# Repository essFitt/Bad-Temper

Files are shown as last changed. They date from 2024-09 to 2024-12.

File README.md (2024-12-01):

This is a remix of the [Temper keyboard](https://github.com/raeedcho/temper). 
The build process and the materials pretty much the same. The reset switch was swapped out for a 6mm tactile button switch. 
To reduce the height of the board, the PCB is not designed to accommodate a base plate. However, I have added a case that is press-fitted and, in my experience, works really well. If printing, you may need to tinker with your tolerances. 

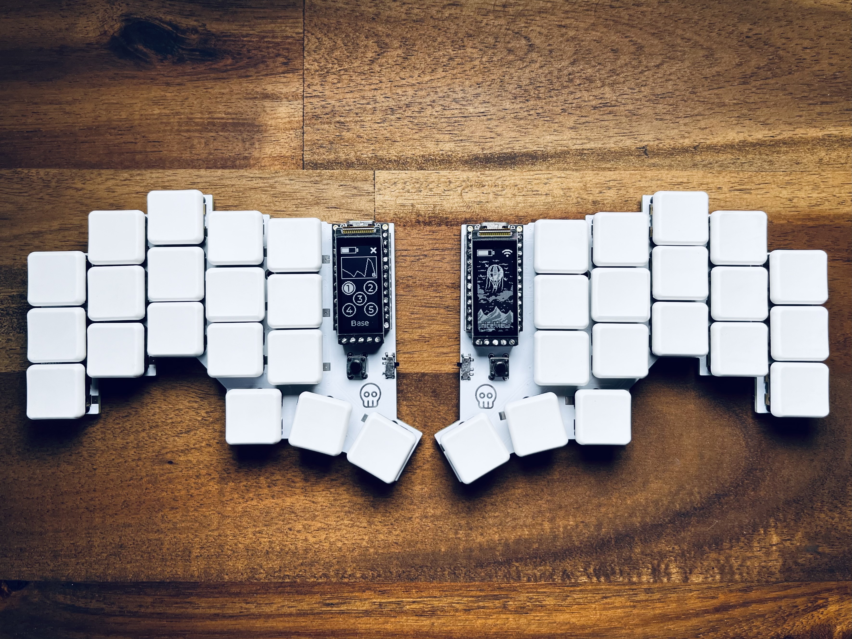
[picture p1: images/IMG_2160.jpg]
Bad Temper top view

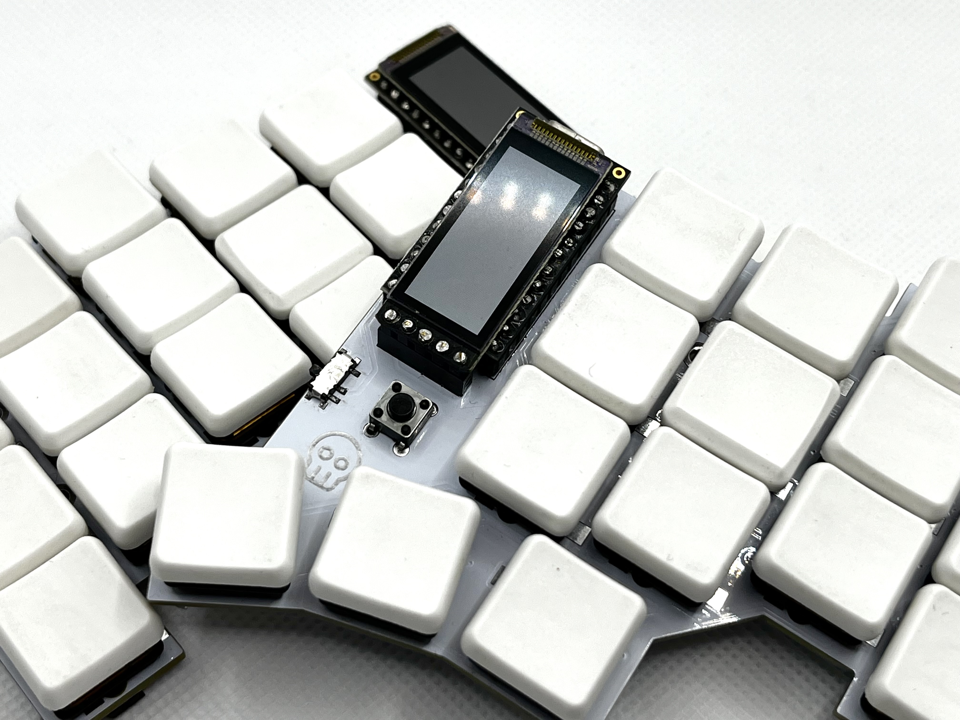
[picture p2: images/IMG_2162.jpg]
Bad Temper close up


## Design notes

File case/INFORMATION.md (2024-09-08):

Please note that the board is not designed to be used with a base plate. I have added a base plate STL file in case anyone wants to edit the PCB to make it work. 
I have found that the switches fit so nicely into the PCB that I do not need a switch plate. They are very snug with no wobble and no chance they will come loose unless deliberately made to do so.

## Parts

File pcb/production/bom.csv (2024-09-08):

Designator | Footprint | Quantity | Value | LCSC Part #
BT1 | Battery_pads_reversible | 1 | Battery_Cell
D1, D10, D11, D12, D13, D14, D15, D16, D17, D18, D2, D3, D4, D5, D6, D7, D8, D9 | D_SMD_TH | 18 | D
J2 | nice_view_jumpers | 1 | nice_view
PWR_SW1 | power_switch_padreverse | 1 | SW_SPDT
RSW1 | SW_PUSH_6mm | 1 | SW_PUSH
SW1, SW10, SW11, SW12, SW13, SW14, SW15, SW16, SW17, SW18, SW2, SW3, SW4, SW5, SW6, SW7, SW8, SW9 | Kailh_socket_PG1350_reversible | 18 | SW_PUSH
U1 | ProMicro_jumpers | 1 | nice_nano

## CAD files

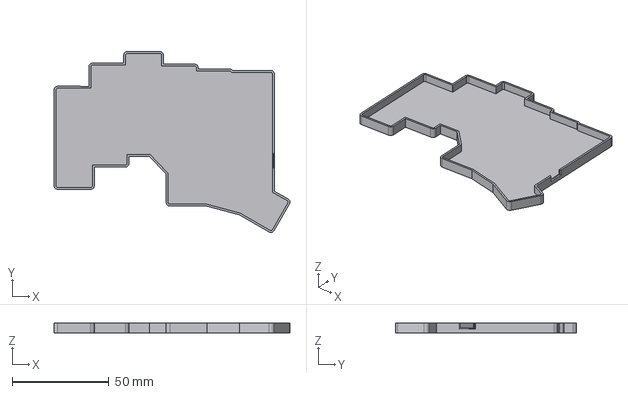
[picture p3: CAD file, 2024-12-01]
case/Case.step
122.0 x 93.6 x 5.00 mm

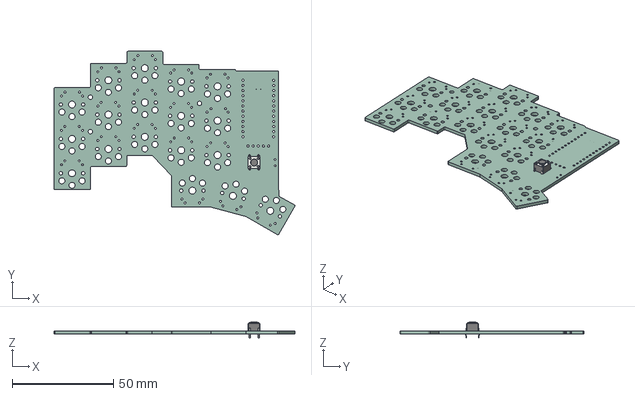
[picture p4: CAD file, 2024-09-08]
pcb/BadTemper.step
119.2 x 90.8 x 7.80 mm
SW_PUSH_6mm
CustomTemper_PCB

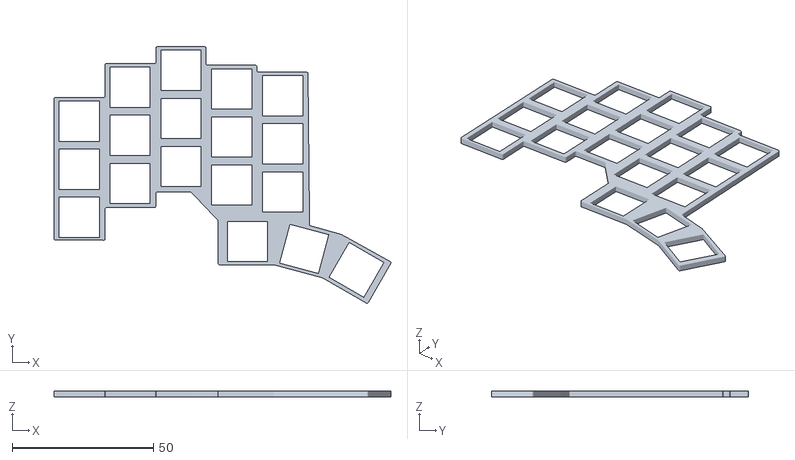
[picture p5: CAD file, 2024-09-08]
case/plate.stl
119.2 x 90.8 x 2.00

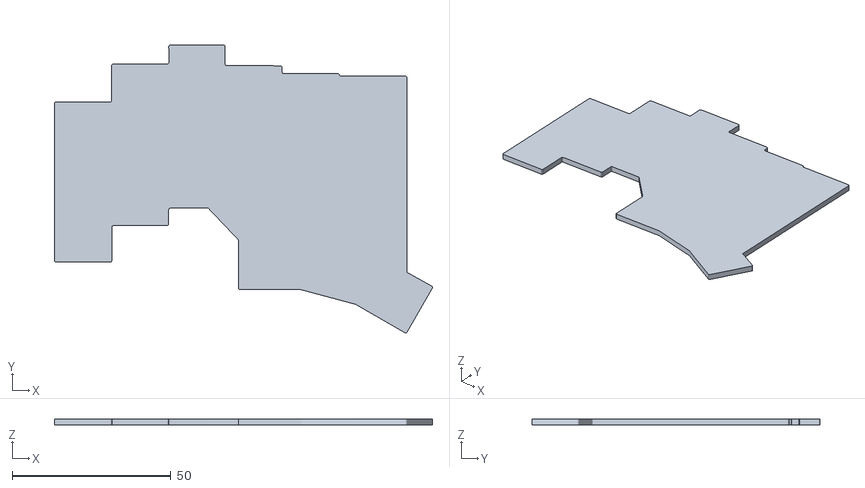
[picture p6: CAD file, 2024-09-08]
case/base plate.stl
119.2 x 90.8 x 2.00

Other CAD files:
case/Case.stl

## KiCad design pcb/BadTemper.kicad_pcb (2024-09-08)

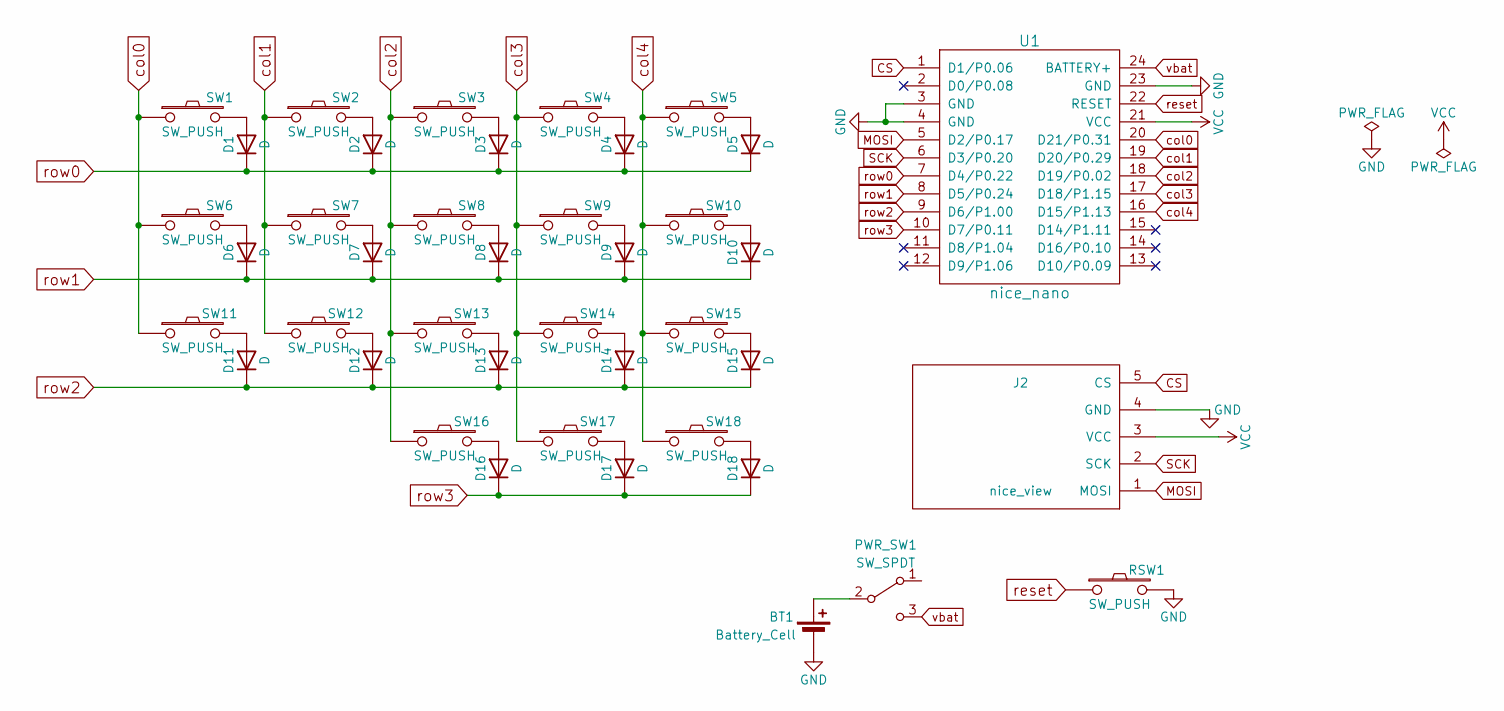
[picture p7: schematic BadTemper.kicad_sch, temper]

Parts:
BT1: Battery_Cell; Battery_pads_reversible
D1, D2, D3, D4, D5, D6, D7, D8, D9, D10, D11, D12, D13, D14, D15, D16, D17, D18: D; D_SMD_TH
J2: nice_view; nice_view_jumpers
PWR_SW1: SW_SPDT; power_switch_padreverse
RSW1: SW_PUSH; SW_PUSH_6mm
SW1, SW2, SW3, SW4, SW5, SW6, SW7, SW8, SW9, SW10, SW11, SW12, SW13, SW14, SW15, SW16, SW17, SW18: SW_PUSH; Kailh_socket_PG1350_reversible
U1: nice_nano; ProMicro_jumpers

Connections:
CS: J2.5 (CS), U1.1 (D1/P0.06)
GND: BT1.2 (-), J2.4 (GND), RSW1.2, U1.3 (GND), U1.4 (GND), U1.23 (GND)
MOSI: J2.1 (MOSI), U1.5 (D2/P0.17)
unnamed: BT1.1 (+), PWR_SW1.2 (B)
unnamed: D1.2 (A), SW1.2
unnamed: D2.2 (A), SW2.2
unnamed: D3.2 (A), SW3.2
unnamed: D4.2 (A), SW4.2
unnamed: D5.2 (A), SW5.2
unnamed: D6.2 (A), SW6.2
unnamed: D7.2 (A), SW7.2
unnamed: D8.2 (A), SW8.2
unnamed: D9.2 (A), SW9.2
unnamed: D10.2 (A), SW10.2
unnamed: D11.2 (A), SW11.2
unnamed: D12.2 (A), SW12.2
unnamed: D13.2 (A), SW13.2
unnamed: D14.2 (A), SW14.2
unnamed: D15.2 (A), SW15.2
unnamed: D16.2 (A), SW16.2
unnamed: D17.2 (A), SW17.2
unnamed: D18.2 (A), SW18.2
SCK: J2.2 (SCK), U1.6 (D3/P0.20)
VCC: J2.3 (VCC), U1.21 (VCC)
col0: SW1.1, SW6.1, SW11.1, U1.20 (D21/P0.31)
col1: SW2.1, SW7.1, SW12.1, U1.19 (D20/P0.29)
col2: SW3.1, SW8.1, SW13.1, SW16.1, U1.18 (D19/P0.02)
col3: SW4.1, SW9.1, SW14.1, SW17.1, U1.17 (D18/P1.15)
col4: SW5.1, SW10.1, SW15.1, SW18.1, U1.16 (D15/P1.13)
reset: RSW1.1, U1.22 (RESET)
row0: D1.1 (K), D2.1 (K), D3.1 (K), D4.1 (K), D5.1 (K), U1.7 (D4/P0.22)
row1: D6.1 (K), D7.1 (K), D8.1 (K), D9.1 (K), D10.1 (K), U1.8 (D5/P0.24)
row2: D11.1 (K), D12.1 (K), D13.1 (K), D14.1 (K), D15.1 (K), U1.9 (D6/P1.00)
row3: D16.1 (K), D17.1 (K), D18.1 (K), U1.10 (D7/P0.11)
vbat: PWR_SW1.3 (C), U1.24 (BATTERY+)

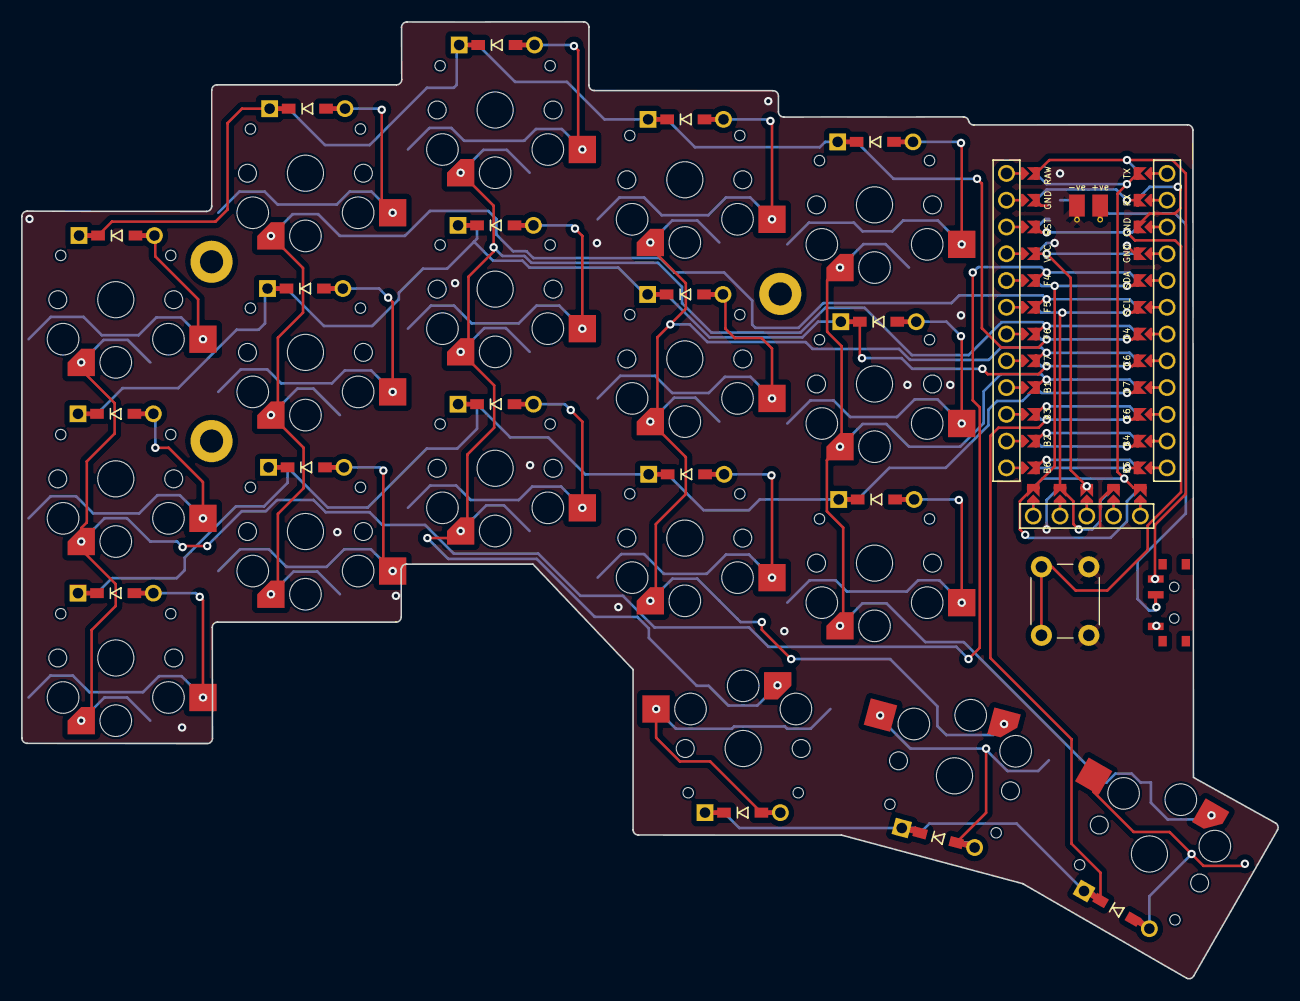
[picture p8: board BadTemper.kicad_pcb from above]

Board: 2 copper layers, 119.2 x 90.8 mm, 44 parts (0 on the bottom side), 35 nets.

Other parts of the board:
h5: h5; LEGO_HOLE
h6: h6; LEGO_HOLE
h7: h7; LEGO_HOLE

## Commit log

2024-12-01 Case files uploaded
    [Case.step, Case.stl]
2024-12-01 Updated case information
2024-12-01 Case information added
